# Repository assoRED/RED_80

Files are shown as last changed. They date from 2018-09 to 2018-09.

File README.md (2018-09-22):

# RED_80 computer

Currently **work in progress.**

# Repository content

# BOM

 - CMOS z80 CPU
 - AS6c62256 32k*8bits CMOS low power SRAM
 - CMOS 4011 quad NAND logic gate
 - CMOS 4071 quad OR logic gate
 - CMOS 40106 hex trigger
 - 1x tactile switch
 - 3x poalized electrolytic 0.01uF capacitor
 - 2x ceramic (unpolarized) 22pF capactitor
 - Crystal (freq. TBD)
 - 1x 10k resistror
 - 1x 1M resistor
 
# Memory map

| memory address | Usage |
| :---: |  :---:  |
|`0x0000` - `0x1FFF`|ROM |
|`0x2000` - `0x3FFF`|EXT ROM| 
|`0x8000` - `0xFFFF`|RAM |

# ROM content

 - `0x0000` system reset/init
 - memroy monitor
 
 # Serial interface
 
 System has been designed to be interfaced with a French Minitel 1B made by MATRA communication terminal.
 
 Serial output is slow (by design). Serial interface configuration : 
 
 - 4800 baud
 - 7bit DATA
 - 1bit STOP
 - Even parity
 - No flow control
 
 To be able to use, you need to setup the minitel in the right comunication mode. Do in order
 
 1) `Fonction`+`T`, `A` Activate "Péri-Informatique" mode
 2) `Fonction`+`T`, `E` Deactivate local character echo
 3) `Fonction`+`P`, `4` Set baudrate to 4800

 Minitel interface can be adapted to serial using the [assoRED/MinitelInterface](https://github.com/assoRED/MinitelInterface) circuit

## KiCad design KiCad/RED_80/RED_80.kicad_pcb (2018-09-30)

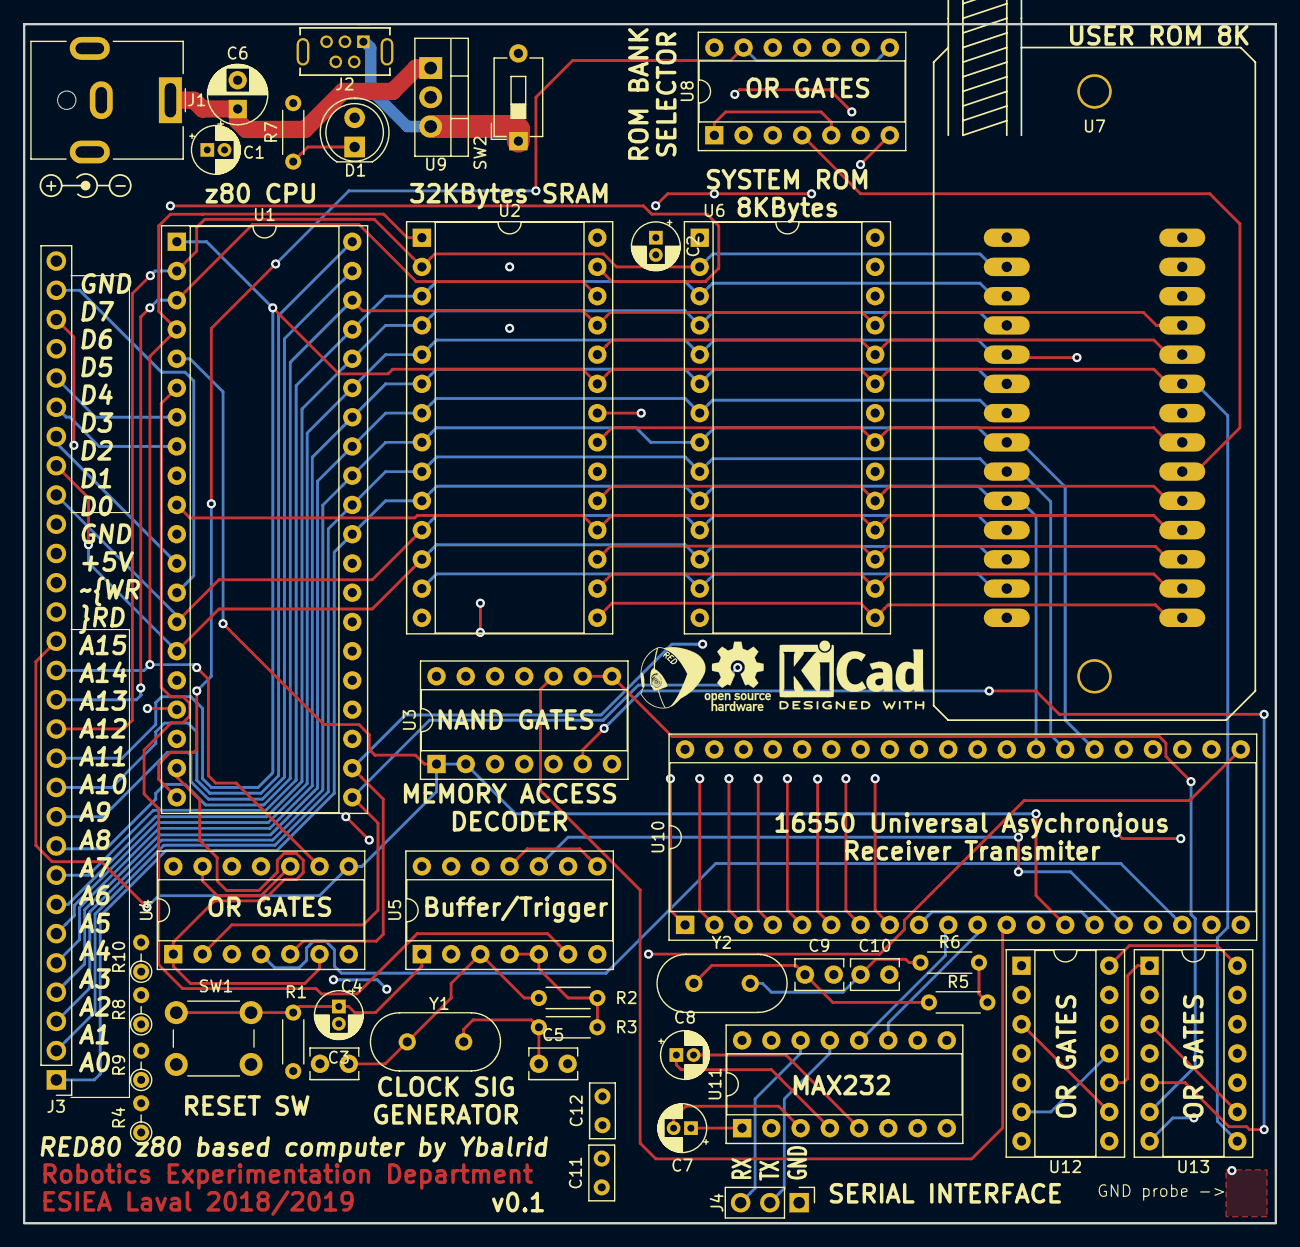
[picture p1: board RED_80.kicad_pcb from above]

Board: 4 copper layers, 108.7 x 104.1 mm, 44 parts (0 on the bottom side), 78 nets.

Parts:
C1, C2: 0.01uF; CP_Radial_D4.0mm_P1.50mm
C3: 0.01uf; CP_Radial_D4.0mm_P1.50mm
C4, C5, C9, C10: 22pF; C_Rect_L4.0mm_W2.5mm_P2.50mm
C6: 100nf; CP_Radial_D5.0mm_P2.50mm
C7, C8: CP; CP_Radial_D4.0mm_P1.50mm
C11, C12: C; C_Rect_L4.6mm_W2.0mm_P2.50mm_MKS02_FKP02
D1: LED; LED_D5.0mm
J1: Barrel_Jack; BarrelJack_CUI_PJ-063AH_Horizontal
J2: USB_B_Micro; USB_Micro-B_Tensility_54-00023_Vertical
J3: Conn_01x29_Male; PinHeader_1x29_P2.54mm_Vertical
J4: Conn_01x03_Male; PinHeader_1x03_P2.54mm_Vertical
R1: 10k; R_Axial_DIN0204_L3.6mm_D1.6mm_P5.08mm_Horizontal
R2, R5: 1M; R_Axial_DIN0204_L3.6mm_D1.6mm_P5.08mm_Horizontal
R3, R6: R; R_Axial_DIN0204_L3.6mm_D1.6mm_P5.08mm_Horizontal
R4, R8, R9, R10: 100k; R_Axial_DIN0204_L3.6mm_D1.6mm_P2.54mm_Vertical
R7: 180; R_Axial_DIN0204_L3.6mm_D1.6mm_P5.08mm_Horizontal
SW1: RESET_SW; SW_PUSH_6mm_H4.3mm
SW2: SW_SPST; SW_DIP_SPSTx01_Slide_6.7x4.1mm_W7.62mm_P2.54mm_LowProfile
U1: Z80CPU; DIP-40_W15.24mm_Socket
U2: AS6C62256; DIP-28_W15.24mm_Socket
U3: 4011; DIP-14_W7.62mm_Socket
U4, U8: 4071; DIP-14_W7.62mm_Socket
U5: 40106; DIP-14_W7.62mm_Socket
U6: 28C64; DIP-28_W15.24mm_Socket
U7: 28C64; 3M-TEXTOOL-ZIF-DIP-28
U9: L7805; TO-220-3_Vertical
U10: 16550; DIP-40_W15.24mm_Socket
U11: MAX232; DIP-16_W7.62mm_Socket
U12, U13: 4075; DIP-14_W7.62mm_Socket
Y1, Y2: Crystal; Crystal_HC18-U_Vertical

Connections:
/A0: J3.1, U1.30, U2.10, U6.11, U7.11, U10.28
/A1: J3.2, U1.31, U2.9, U6.12, U7.12, U10.27
/A2: J3.3, U1.32, U2.8, U6.13, U7.13, U10.26
/A3: J3.4, U1.33, U2.7, U6.15, U7.15, U12.1
/A4: J3.5, U1.34, U2.6, U6.16, U7.16, U12.2
/A5: J3.6, U1.35, U2.5, U6.17, U7.17, U12.8
/A6: J3.7, U1.36, U2.4, U6.18, U7.18, U12.4
/A7: J3.8, U1.37, U2.3, U6.19, U7.19, U12.5
/A8: J3.9, U1.38, U2.25, U12.12
/A9: J3.10, U1.39, U2.24, U12.13
/A10: J3.11, U1.40, U2.21, U13.2
/A11: J3.12, U1.1, U2.23, U13.8
/A12: J3.13, U1.2, U2.2, U13.4
/A13: J3.14, U1.3, U2.26, U13.5
/A14: J3.15, U1.4, U2.1, U10.13
/A15: J3.16, U1.5, U3.1, U3.2, U10.14
/CPU_BUSRQ: R4.2, U1.25
/CPU_INT: R9.2, U1.16
/CPU_NMI: R10.2, U1.17
/CPU_WAIT: R8.2, U1.24
/D0: J3.21, U1.14, U2.11, U6.10, U7.10, U10.1
/D1: J3.22, U1.15, U2.12, U6.9, U7.9, U10.2
/D2: J3.23, U1.12, U2.13, U6.8, U7.8, U10.3
/D3: J3.24, U1.8, U2.15, U6.7, U7.7, U10.4
/D4: J3.25, U1.7, U2.16, U6.6, U7.6, U10.5
/D5: J3.26, U1.9, U2.17, U6.5, U7.5, U10.6
/D6: J3.27, U1.10, U2.18, U6.4, U7.4, U10.7
/D7: J3.28, U1.13, U2.19, U6.3, U7.3, U10.8
/RED_80_PowerInput/DC+5: J2.1, SW2.1, U9.3
/RED_80_PowerInput/DC_IN: C6.1, J1.1, U9.1
/RED_80_Ram/RAM_ENABLE: U2.20, U3.3
/RED_80_Roms/A8: U6.25, U7.25
/RED_80_Roms/A9: U6.24, U7.24
/RED_80_Roms/A10: U6.21, U7.21
/RED_80_Roms/A11: U6.23, U7.23
/RED_80_Roms/A12: U6.2, U7.2
/RED_80_Roms/USER_ROM_SELECTED: U3.4, U8.6
/RED_80_SERIAL/SERIAL_CLOCK: U5.10, U10.16
CPU_CLK: U1.6, U5.6
GND: C1.2, C2.2, C3.2, C4.2, C5.2, C6.2, C9.2, C10.2, C12.2, J1.2, J2.5, J2.6, J3.20, J3.29, J4.1, R7.2, SW1.2, U1.29, U2.14, U3.7, U4.7, U5.7, U6.14, U6.22, U7.14, U7.22, U8.7, U9.2, U10.19, U10.20, U10.22, U10.25, U11.15, U12.7, U13.7
MAIN_5V: C1.1, C2.1, C11.2, D1.2, J3.19, R1.1, R4.1, R8.1, R9.1, R10.1, SW2.2, U1.11, U2.28, U3.14, U4.14, U5.14, U6.27, U6.28, U7.27, U7.28, U8.14, U10.40, U11.16, U12.14, U13.14
unnamed: C3.1, R1.2, SW1.1, U5.1
unnamed: C4.1, R2.2, U5.3, Y1.1
unnamed: C5.1, R3.2, Y1.2
unnamed: C7.1, U11.1
unnamed: C7.2, U11.3
unnamed: C8.1, U11.4
unnamed: C8.2, U11.5
unnamed: C9.1, R5.2, U5.9, Y2.1
unnamed: C10.1, R6.2, Y2.2
unnamed: C11.1, U11.2
unnamed: C12.1, U11.6
unnamed: D1.1, R7.1
unnamed: R2.1, R3.1, U5.4, U5.5
unnamed: R5.1, R6.1, U5.8, U5.11
unnamed: U1.19, U4.1, U4.6
unnamed: U1.20, U8.8, U8.13
unnamed: U1.21, U4.2, U8.9
unnamed: U1.22, U4.5, U8.12
unnamed: U4.10, U4.13
unnamed: U10.10, U11.12
unnamed: U10.11, U11.11
unnamed: U3.10, U10.12
unnamed: U10.9, U10.15
unnamed: U12.3, U12.9
unnamed: U12.10, U13.1
unnamed: U12.6, U12.11
unnamed: U13.3, U13.9
unnamed: U3.8, U3.9, U13.6
ROM_BANK_ON: U4.11, U8.1, U8.5
RS232_RX: J4.2, U11.13
RS232_TX: J4.3, U11.14
SIG_MRD: J3.17, U2.22, U4.3, U4.12, U10.21
SIG_MWR: J3.18, U2.27, U4.4, U10.18
SIG_RST: U1.26, U5.2
SYS_ROM_ENABLE: U6.20, U8.3
SYS_USER_SELECT: U3.5, U3.6, U8.2
USER_ROM_ENABLE: U7.20, U8.4

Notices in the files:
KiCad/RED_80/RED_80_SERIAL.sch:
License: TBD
